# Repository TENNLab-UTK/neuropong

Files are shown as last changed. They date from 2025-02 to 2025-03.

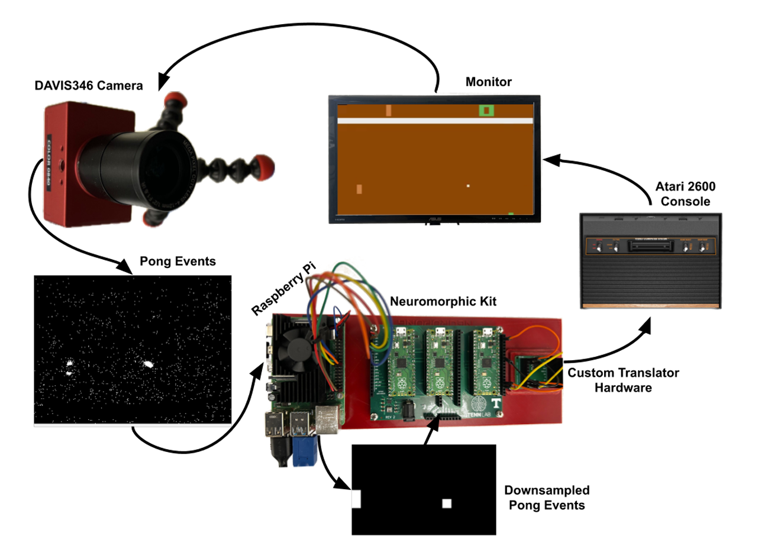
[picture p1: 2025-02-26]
imgs/NeuroPong_Physical_System.png

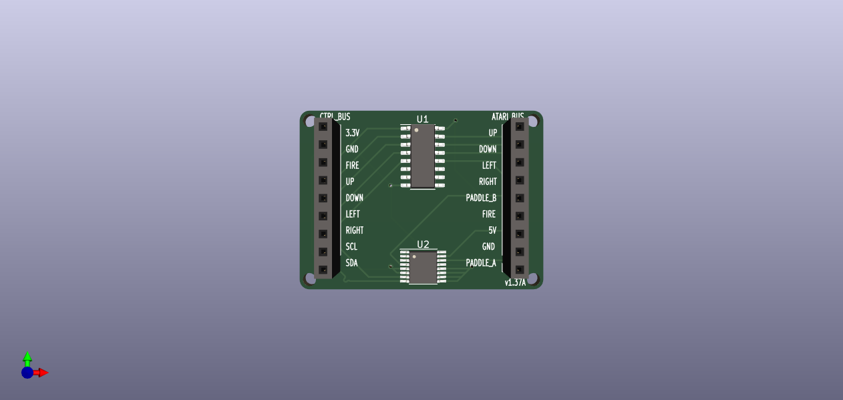
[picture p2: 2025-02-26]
pcb/pcb_v1_37A/ATARI_CTRL_PCB_1.37A_2.54mm.png

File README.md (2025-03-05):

# Neuropong
This is the repo contains the NeuroPong project files. NeuroPong is an embedded, neuromorphic Atari (Pong) agent. It marries an event-based camera, TENNLab's Neuromorphic Starter Kit (https://arxiv.org/abs/2211.04526), and an Atari 2600 console. Spiking neural networks are trained on simulated events created from frames generated by the Arcade Learning Environment, and then, those spiking neural networks are put on hardware to examine how they perform in a live setting using real event camera inputs.

## Prerequisites
Repositories needed to run existing spiking neural network agents:

- TENNLab Open-Source Framework: https://github.com/TENNLab-UTK/framework-open
- Inivation `dv-processing` Library: https://gitlab.com/inivation/dv/dv-processing
- TENNLab Embedded Neuromorphic repository(*):
    - Needed to compile code for Neuromorphic Starter Kit's Raspberry Pi Picos

(*) You will need to get access to this repo from Jim Plank (jplank@utk.edu) until it is open-sourced.

You will also need Python and a shell of some kind (bash/zsh) on Linux or Mac. It is recommended to set up a python virtual environment (Python <= 3.9) for compatability with Inivation event camera library.

## Contents

- **/models**: STL models of 3D printed objects used in this project for the presented prototype

- **/kit-code**: Contains code used by `embedded-neuromorphic/` repo to compile kit code.

- **/pcb**: Repo containing KiCad files for the PCB that contains the Atari Translator circuit

- **/scripts**: Scripts used to assist with flashing Picos and compiling kit code. `calibration.py` and `event_server.py` are used on the Raspberry Pi (or whatever is communicating with the Neuromorphic Starter Kit)

- **/imgs**: Contains various diagrams and images detailing parts of the NeuroPong system

- **/networks**: Contains the networks generated for the Neuropong paper.  

## Table of Hardware Materials/Components

| | Part | Quantity | Cost |
|:--:| ---: | ---: | ----: |
| | PCB Design |  1 | $4.11 |
| | AD5242 | 1 | $4.55 |
| | ULN2008 |  1 (unused) | $3.95 |
| | Female pin strips |  2 | $26.00 |
| | Raspberry Pi 4 |  1  | $75.00 |
| | MicroSD Card |  1 | $13.50 |
| | Breakout Cable |  1 | $20.00 |
|**Neuromorphic Starter Kit** |  | |  |
| | PCB Design |  1  | $10.65 |
| | Raspberry Pi Pico | 3 | $15.00 |
| | Power Supply | 1 | $7.69 |
| **Total** | | | $180.45 | 

* The Atari 2600 console and VideoOlympics cartridge together were ~$20.00.
* The DAVIS346 camera used for this project was purchased from [Inivation] (https://shop.inivation.com/).

## Running the Hardware Setup

1. Turn on monitor, put VideoOlympics cartridge in Atari 2600 console, and turn on the Atari console.
    - You should see the Pong game appear on the screen.
2. Plug NeuroPong controller into the back of one of the Atari controller ports.
    - *NOTE: you will need to make the NeuroPong cable. An detailed construction diagram can be found in the `/imgs` folder*
4. Power on the Raspberry Pi, and plug DAVIS346 camera into one of the USB ports on the Raspberry Pi.
5. Compile the network using `app_compile` from the `embedded_neuromorphic/` repo
    - Ex: `./bin/app_compile -j network_file -o kit-code/pico-pong_observations.c -a kit-code/pico-pong_actions[2,3].c -s`
6. Flash the three Raspberry Pi Picos on the kit with the appropriate encoder, decoder, and network. 
7. Power on the Neuromorphic Kit
8. On the Raspberry Pi, run `scripts/calibration.py` to assist with focusing the lens and cropping the camera's FOV to the screen.
    - The output produced by `scripts/calibration.py` is the command that is used to run `scripts/event_server.py`.
        - It figures out what the crop coordinates are and what the downsampling parameters need to be to match whatever the target downsampled resolution is. Target resolution is specified via global variables in the `scripts/calibration.py` program.
9. Run the command output by `scripts/calibration.py`
    - Ex: `python3 event_server.py --crop ...`
10. Wait 20-30 seconds for the system to initialize. If it's unreponsive, CTRL-C the event_server process and rerun it.
11. Begin the Atari game by toggling the ``Game Reset'' switch on the Atari system.
     
## Running the networks in the `framework-open` processor_tool

You may want to run the networks using `framework-open/bin/processor_tool` in order to view spike rasters for a network at each timestep during an episode of that network playing Pong in the Arcade Learning Environment. In `networks/processor_tool_commands` are the commands for the processor tool, for each of the 32 networks, for one 2000 frame Pong episode each. Each file in `networks/processor_tool_commands` contains the Apply_Spike (AS) commands that communicate the event simulated and downsampled representation of each frame as they're generated by the ALE online. To run, do the following:

            ```
            UNIX> pwd
            .../neuropong
            UNIX> ./framework-open/bin/processor_tool_risp < networks/processor_tool_commands/pong0.txt
            0   INPUT  :    // No inputs are provided to the network during the first frame or timestep, so the spike raster is empty
            1   INPUT  : 
            2   INPUT  : 
            3   INPUT  : 
            4   INPUT  : 
            5   INPUT  : 
            6   INPUT  : 
            7   INPUT  : 
            8   INPUT  : 
            9   INPUT  : 
            10  INPUT  : 
            11  INPUT  : 
            12  INPUT  : 
            13  INPUT  : 
            14  INPUT  : 
            15  INPUT  : 
            16  INPUT  : 
            17  INPUT  : 
            18  INPUT  : 
            19  INPUT  : 
            20  INPUT  : 
            21  INPUT  : 
            22  INPUT  : 
            23  INPUT  : 
            24  INPUT  : 
            25  INPUT  : 
            26  INPUT  : 
            27  INPUT  : 
            28  INPUT  : 
            29  INPUT  : 
            30  INPUT  : 
            31  INPUT  : 
            32  INPUT  : 
            33  INPUT  : 
            34  INPUT  : 
            35  INPUT  : 
            36  INPUT  : 
            37  INPUT  : 
            38  INPUT  : 
            39  INPUT  : 
            40  INPUT  : 
            41  INPUT  : 
            42  INPUT  : 
            43  INPUT  : 
            44  INPUT  : 
            45  INPUT  : 
            46  INPUT  : 
            47  INPUT  : 
            48  INPUT  : 
            49  INPUT  : 
            50  INPUT  : 
            51  INPUT  : 
            52  INPUT  : 
            53  INPUT  : 
            54  INPUT  : 
            55  INPUT  : 
            56  INPUT  : 
            57  INPUT  : 
            58  INPUT  : 
            59  INPUT  : 
            60  INPUT  : 
            61  INPUT  : 
            62  INPUT  : 
            63  INPUT  : 
            64  INPUT  : 
            65  INPUT  : 
            66  INPUT  : 
            67  INPUT  : 
            68  INPUT  : 
            69  INPUT  : 
            70  INPUT  : 
            71  INPUT  : 
            72  INPUT  : 
            73  INPUT  : 
            74  INPUT  : 
            75  INPUT  : 
            76  INPUT  : 
            77  INPUT  : 
            78  INPUT  : 
            79  INPUT  : 
            80  INPUT  : 
            81  INPUT  : 
            82  INPUT  : 
            83  INPUT  : 
            84  INPUT  : 
            85  INPUT  : 
            86  INPUT  : 
            87  INPUT  : 
            88  INPUT  : 
            89  INPUT  : 
            90  INPUT  : 
            91  INPUT  : 
            92  INPUT  : 
            93  INPUT  : 
            94  INPUT  : 
            95  INPUT  : 
            96  INPUT  : 
            97  INPUT  : 
            98  INPUT  : 
            99  INPUT  : 
            100 INPUT  : 
            101 INPUT  : 
            102 INPUT  : 
            103 INPUT  : 
            104 INPUT  : 
            105 INPUT  : 
            106 INPUT  : 
            107 INPUT  : 
            108 INPUT  : 
            109 INPUT  : 
            110 INPUT  : 
            111 INPUT  : 
            112 INPUT  : 
            113 INPUT  : 
            114 INPUT  : 
            115 INPUT  : 
            116 INPUT  : 
            117 INPUT  : 
            118 INPUT  : 
            119 INPUT  : 
            120 INPUT  : 
            121 INPUT  : 
            122 INPUT  : 
            123 INPUT  : 
            124 INPUT  : 
            125 INPUT  : 
            126 INPUT  : 
            127 INPUT  : 
            128 INPUT  : 
            129 INPUT  : 
            130 INPUT  : 
            131 INPUT  : 
            132 INPUT  : 
            133 INPUT  : 
            134 INPUT  : 
            135 INPUT  : 
            136 INPUT  : 
            137 INPUT  : 
            138 INPUT  : 
            139 INPUT  : 
            140 INPUT  : 
            141 INPUT  : 
            142 INPUT  : 
            143 INPUT  : 
            144 INPUT  : 
            145 INPUT  : 
            146 INPUT  : 
            147 INPUT  : 
            148 INPUT  : 
            149 INPUT  : 
            150 INPUT  : 
            151 INPUT  : 
            152 INPUT  : 
            153 INPUT  : 
            154 INPUT  : 
            155 INPUT  : 
            156 INPUT  : 
            157 INPUT  : 
            158 INPUT  : 
            159 INPUT  : 
            160 OUTPUT : 
            161 OUTPUT : 
            162 OUTPUT : 
            0   INPUT  : 1000000000100100100000000000000000000000000000000 // Now, during the second frame/timestep, we apply a spike to  
            1   INPUT  : 1000000000000000000000000000000000000000000000000 // the appropriate input neurons and run the network for 50 cycles. 
            2   INPUT  : 1010000001000000010011000000000010000000000000000 // The columns represent the network timestep 
            3   INPUT  : 1000000000000000000000000000000000000000000000000 // and a "1" represents a neuronal fire.
            4   INPUT  : 1000000000000111100100100000001000100000000001000
            5   INPUT  : 1000000000000000000000000000000000000000000000000
            6   INPUT  : 1000000000000000000000000000000000000000000000000
            7   INPUT  : 1000000000000000000000000000000000000000000000000
            8   INPUT  : 1000000000000000000000000000000000000000000000000
            9   INPUT  : 1000000000000000000000000000000000000000000000000
            10  INPUT  : 1000000000000000000000000000000000000000000000000
            11  INPUT  : 1000000000000000000000000000000000000000000000000
            12  INPUT  : 1000000000000000000000000000000000000000000000000
            13  INPUT  : 1000000000000000000000000000000000000000000000000
            14  INPUT  : 1000000000000000000000000000000000000000000000000
            15  INPUT  : 1000000000000000000000000000000000000000000000000
            16  INPUT  : 1000000000100000000000000000000000000000000000000
            17  INPUT  : 1000000000000000000000000000000000000000000000000
            18  INPUT  : 1000000000000000000000000000000000000000000000000
            19  INPUT  : 1000000000000000000000000000000000000000000000000
            20  INPUT  : 1000000000000010000000000000000000000000000000000
            21  INPUT  : 1000000000000000000000000000000000000000000000000
            22  INPUT  : 1000000001000000000000000000000000000000000000000
            23  INPUT  : 1001000000000000000000000000000000000000000000000
            24  INPUT  : 1000000000000000000000000000000000000000000000000
            25  INPUT  : 1000000000000000000000000000000000000000000000000
            26  INPUT  : 1000000000000000000000000000000000000000000000000
            27  INPUT  : 1000010000000000000000000000000000000000000000000
            28  INPUT  : 1000000000000000000000000000000000000000000000000
            29  INPUT  : 1000000001010000000000000000000000000000000000000
            30  INPUT  : 1000000000000000000000000000000000000000000000000
            31  INPUT  : 1000000000000000000000000000000000000000000000000
            32  INPUT  : 1000000000000000000000000000000000000000000000000
            33  INPUT  : 1000000000000000000000000000000000000000000000000
            34  INPUT  : 1000000000000000000000000000000000000000000000000
            35  INPUT  : 1000000000000000000000000000000000000000000000000
            36  INPUT  : 1000000000000000000000000000000000000000000000000
            37  INPUT  : 1000000000000000000000000000000000000000000000000
            38  INPUT  : 1000000010000000000000000000000000000000000000000
            39  INPUT  : 1000000000000000000000000000000000000000000000000
            40  INPUT  : 1000000000010000000000000000000000000000000000000
            41  INPUT  : 1000000000000000000000000000000000000000000000000
            42  INPUT  : 1000000000000000000000000000000000000000000000000
            43  INPUT  : 1000000000000000000000000000000000000000000000000
            44  INPUT  : 1000000000000000000000000000000000000000000000000
            45  INPUT  : 1000000000000000000000000000000000000000000000000
            46  INPUT  : 1000000000000000000000000000000000000000000000000
            47  INPUT  : 1000000000000000000000000000000000000000000000000
            48  INPUT  : 1000000000010000000000000000000000000000000000000
            49  INPUT  : 1000000000000000000000000000000000000000000000000
            50  INPUT  : 1000000000010000000000000000000000000000000000000
            51  INPUT  : 1000000100000000000000000000000000000000000000000
            52  INPUT  : 1000000000000000000000000000000000000000000000000
            53  INPUT  : 1000000000000000000000000000000000000000000000000
            54  INPUT  : 1000000000000000000000000000000000000000000000000
            55  INPUT  : 1000000000000000000000000000000000000000000000000
            56  INPUT  : 1000000000000000000000000000000000000000000000000
            57  INPUT  : 1000000000000000000000000000000000000000000000000
            58  INPUT  : 1001010000000110000000000001111001001000000010001
            59  INPUT  : 1000100000000001000000000000000000000000000000000
            60  INPUT  : 1000000000000000000000000000000000000000000000000
            61  INPUT  : 1000000000010000000000000000000000000000000000000
            62  INPUT  : 1000000000000000000000000000000000000000000000000
            63  INPUT  : 1000000000000000000000000000000000000000000000000
            64  INPUT  : 1100010100100100000000000000000000000000000000000
            65  INPUT  : 1000000000000000000000000000000000000000000000000
            66  INPUT  : 1010010010000000000000000000000000000000000000000
            67  INPUT  : 1000000000010000000000000000000000000000000000000
            68  INPUT  : 1000000000000000000000000000000000000000000000000
            69  INPUT  : 1001000000000000000000000000000000000000000000000
            70  INPUT  : 1000010000000000000000000000000000000000000000000
            71  INPUT  : 1000000000000000000000000000000000000000000000000
            72  INPUT  : 1000000000000000000000000000000000000000000000000
            73  INPUT  : 1000000000000000000000000000000000000000000000000
            74  INPUT  : 1000000000000000000000000000000000000000000000000
            75  INPUT  : 1000000000000001000000000000000000000000000000000
            76  INPUT  : 1000000000000000000000000000000000000000000000000
            77  INPUT  : 1000000000000000000000000000000000000000000000000
            78  INPUT  : 1001011000100000000000000100000000000000000000000
            79  INPUT  : 1000000000000000000000000000000000000000000000000
            80  INPUT  : 1000000000000000000000000000000000000000000000000
            81  INPUT  : 1000000000000000000000000000000000000000000000000
            82  INPUT  : 1000000000000000000000000000000000000000000000000
            83  INPUT  : 1000000000000000000000000000000000000000000000000
            84  INPUT  : 1000000000000000000000000000000000000000000000000
            85  INPUT  : 1000000000000000000000000000000000000000000000000
            86  INPUT  : 1000000000000000000000000000000000000000000000000
            87  INPUT  : 1000000000000000000000000000000000000000000000000
            88  INPUT  : 1000000000000000000000000000000000000000000000000
            89  INPUT  : 1000000000000000000000000000000000000000000000000
            90  INPUT  : 1000000000000000000000000000000000000000000000000
            91  INPUT  : 1000000000000000000000000000000000000000000000000
            92  INPUT  : 1000000000000000000000000000000000000000000000000
            93  INPUT  : 1000000000000000000000000000000000000000000000000
            94  INPUT  : 1000000000000000000000000000000000000000000000000
            95  INPUT  : 1000000000000000000000000000000000000000000000000
            96  INPUT  : 1000000000100001000000000010000000000000000000000
            97  INPUT  : 1000000000000000000000000000000000000000000000000
            98  INPUT  : 1010000000000000000000000000000000000000000000000
            99  INPUT  : 1000000000000000000000000000000000000000000000000
            100 INPUT  : 1000000000000000000000000000000000000000000000000
            101 INPUT  : 1000000100000000000000000000000000000000000000000
            102 INPUT  : 1000000000000000000000000000000000000000000000000
            103 INPUT  : 1000000000000000000000000000000000000000000000000
            104 INPUT  : 1000000000000000000000000000000000000000000000000
            105 INPUT  : 1000000000000000000000000000000000000000000000000
            106 INPUT  : 1000000000000000000000000000000000000000000000000
            107 INPUT  : 1000000000000000000000000000000000000000000000000
            108 INPUT  : 1000000000000000000000000000000000000000000000000
            109 INPUT  : 1000000000000000000000000000000000000000000000000
            110 INPUT  : 1000000000000000000000000000000000000000000000000
            111 INPUT  : 1000000000000000000000000000000000000000000000000
            112 INPUT  : 1000000000000000000000000000000000000000000000000
            113 INPUT  : 1001001000000000000000000000000000000000000000000
            114 INPUT  : 1000000000000000000000000000000000000000000000000
            115 INPUT  : 1000000000000000000000000000000000000000000000000
            116 INPUT  : 1000000000000000000000000000000000000000000000000
            117 INPUT  : 1000000000000000000000000000000000000000000000000
            118 INPUT  : 1000000000100000000000010000000000100000000000000
            119 INPUT  : 1000000000000000000000000000000000000000000000000
            120 INPUT  : 1000000000000100000000001000000000000000000000000
            121 INPUT  : 1000000000000000000000000000000000000000000000000
            122 INPUT  : 1010000000000000010000000000000000000000000000000
            123 INPUT  : 1000000000000000000000000000000000000000000000000
            124 INPUT  : 1000000000000000000000000000000000000000000000000
            125 INPUT  : 1000000000000000000000000000000000000000000000000
            126 INPUT  : 1000000000000000000000000000000000000000000000000
            127 INPUT  : 1000000000000000000000000000000000000000000000000
            128 INPUT  : 1000000000000000000000000000000000000000000000000
            129 INPUT  : 1011000100000000000000100000000000000000000000000
            130 INPUT  : 1000000000000000000000000000000000000000000000000
            131 INPUT  : 1000000000000000000000000000000000000000000000000
            132 INPUT  : 1000000000000000000000000000000000000000000000000
            133 INPUT  : 1000000000000001000000000000000000000000000000000
            134 INPUT  : 1000000000000000000000000000000000000000000000000
            135 INPUT  : 1010000000000000000000000000000000000000000000000
            136 INPUT  : 1000000000000000000000000000000000000000000000000
            137 INPUT  : 1000000000000000000000000000000000000000000000000
            138 INPUT  : 1000000000000000000000000000000000000000000000000
            139 INPUT  : 1000000000000000000000000000000000000000000000000
            140 INPUT  : 1000000000000000000000000000000000000000000000000
            141 INPUT  : 1000000000000000000000000000000000000000000000000
            142 INPUT  : 1000000010000000000000000000000000000000000000000
            143 INPUT  : 1000000000000000000000000000000000000000000000000
            144 INPUT  : 1000000100000001000100000000001000000000000000000
            145 INPUT  : 1000000000000000000000000000000000000000000000000
            146 INPUT  : 1000000000000000000000000000000000000000000000000
            147 INPUT  : 1000000000000000000000000000000000000000000000000
            148 INPUT  : 1000100000000000000000000000000000000000000000000
            149 INPUT  : 1000000000000000000000000000000000000000000000000
            150 INPUT  : 1100010000000000000010000000000000000000000000000
            151 INPUT  : 1000000000000000000000000000000000000000000000000
            152 INPUT  : 1000000000000000000000000000000000000000000000000
            153 INPUT  : 1000000000000000000000000000000000000000000000000
            154 INPUT  : 1010000000000000000000000000000000000000000000000
            155 INPUT  : 1000000000000000000000000000000000000000000000000
            156 INPUT  : 1000000000000000000000000000000000000000000000000
            157 INPUT  : 1000000000000000000000000000000000000000000000000
            158 INPUT  : 1000000100000010000000000000000000000000000000000
            159 INPUT  : 1000000000000000000000000000000000000000000000000
            160 OUTPUT : 0000100101000000011000000000000111100100100000001 // At the end of our 50 timesteps, we count the output fires on the
            161 OUTPUT : 0000000010000000000000000000000000000000000000000 // three output neurons. Whoever fired the most "wins", and its
            162 OUTPUT : 0000000001000100000000000000000000000000000000000 // action is the action performed by the network for that frame
            ...                                                            // from the ALE.
            ...
            ```

More information about `processor_tool_risp` can be found in the `framework-open/markdown/` directory. This is provided as a method for you to see how the network acts when provided event-simulated and downsampled ALE frames.

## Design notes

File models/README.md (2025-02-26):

# 3d Models used in this project
These files include the chassis that held individual components and the PCB enclosure for the Atari Translator PCB Module.

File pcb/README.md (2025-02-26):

# Atari CTRL PCB
This folder contains the KiCad source files along with some renders of what the PCB looks like

# Components
1. Digital Potentiometer - AD5242
    - Function: Emulate paddle controller analogue signal
    - https://www.digikey.com/en/products/detail/analog-devices-inc/AD5242BRUZ1M/997427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
2. Darlington Transistor Pair - ULN2003A
    - Function: Emulate button presses from joystick controller (negative logic)
    - Note: When button is pressed, the input pin (UP/DOWN/LEFT/RIGHT/FIRE) is shorted from floating voltage to ground (0 V)
    - https://www.digikey.com/en/products/detail/texas-instruments/ULN2003ADR/277011

## Case Incompatability Disclosure 
**NOTE**: The PCB Case Lid is only compatible with 1.25A version of the case. This is due to the connector size changes from 2.00mm connector (v1.27) to a 2.54mm connector (1.37A). 

## Pinout Disclosure
**NOTE**: The PCB design does not utilize the 5V rail from the Atari to avoid voltage mismatches on the digital potentiometer output.

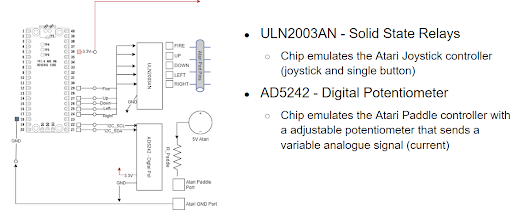
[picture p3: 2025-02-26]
imgs/decoderDiagram.png

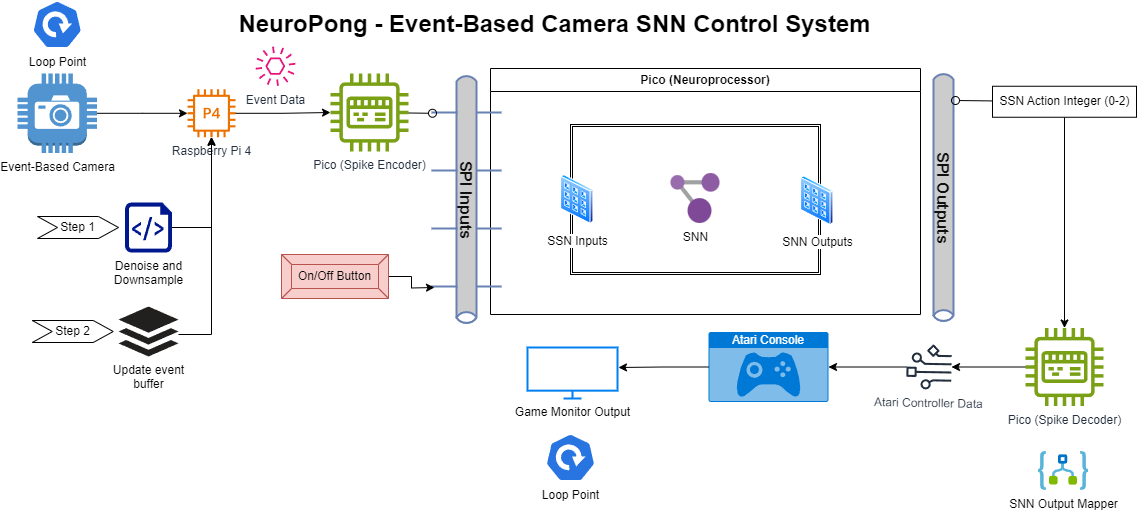
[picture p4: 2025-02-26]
imgs/NeuroPong_System_Diagram-System Diagram.png

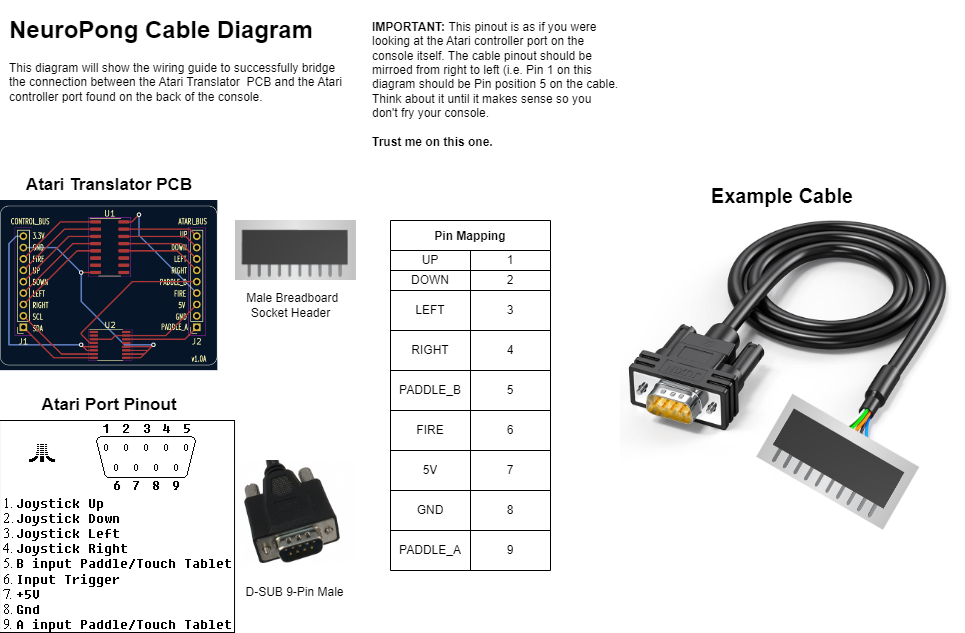
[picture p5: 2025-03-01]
imgs/NeuroPong_Cable.drawio.png

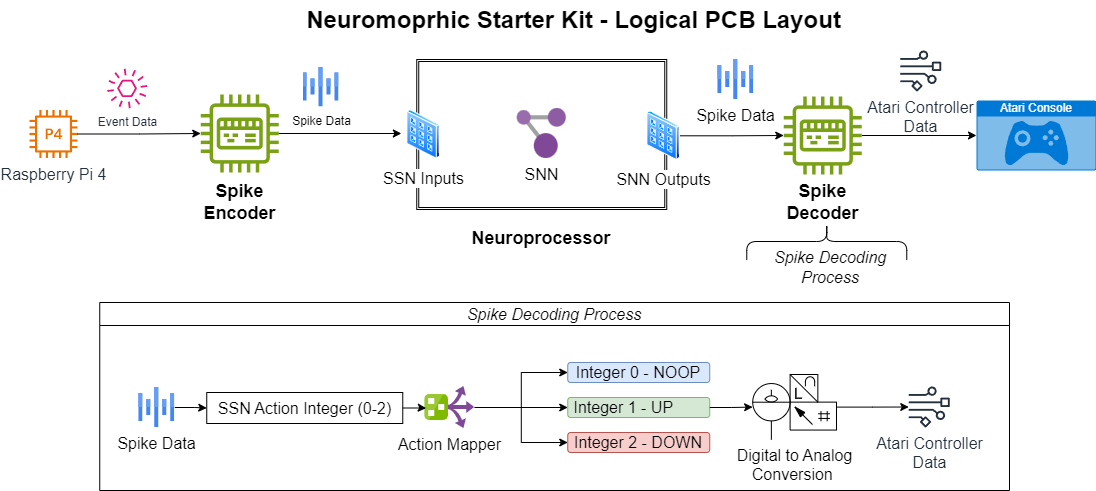
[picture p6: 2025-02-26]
imgs/NeuroPong_System_Diagram-System Data Flow.png

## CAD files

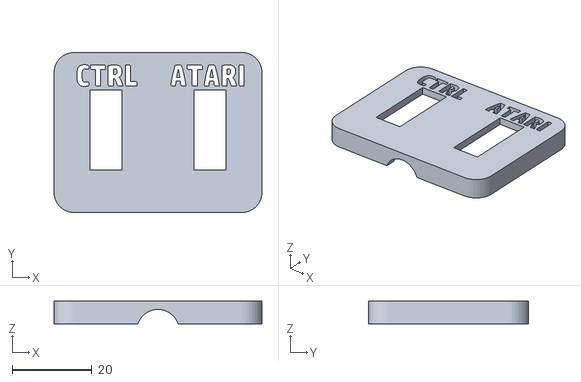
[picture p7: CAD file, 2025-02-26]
models/pcb_case/ATARI_Enclosure_Lid.STL
52.0 x 40.0 x 5.63

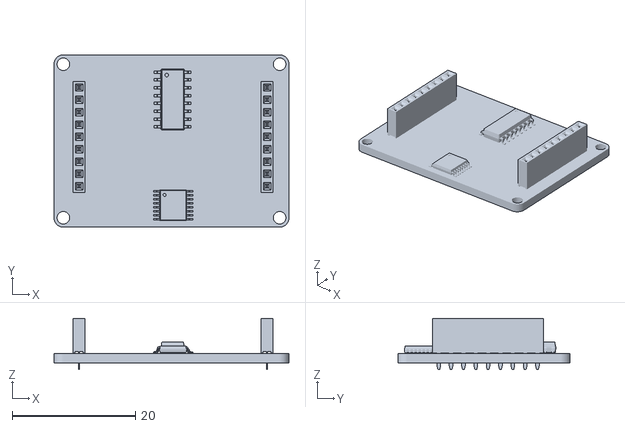
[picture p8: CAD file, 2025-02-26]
models/pcb_case/ATARI PCB.STL
38.1 x 27.9 x 8.30

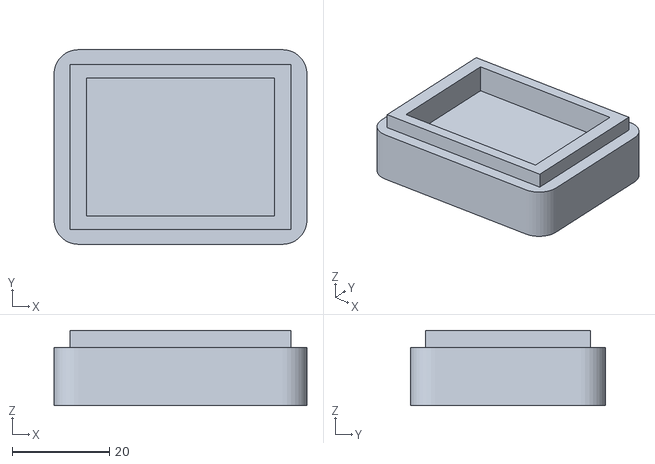
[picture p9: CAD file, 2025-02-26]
models/pcb_case/ATARI_CTRL_PCB Case.STL
52.0 x 40.0 x 15.5

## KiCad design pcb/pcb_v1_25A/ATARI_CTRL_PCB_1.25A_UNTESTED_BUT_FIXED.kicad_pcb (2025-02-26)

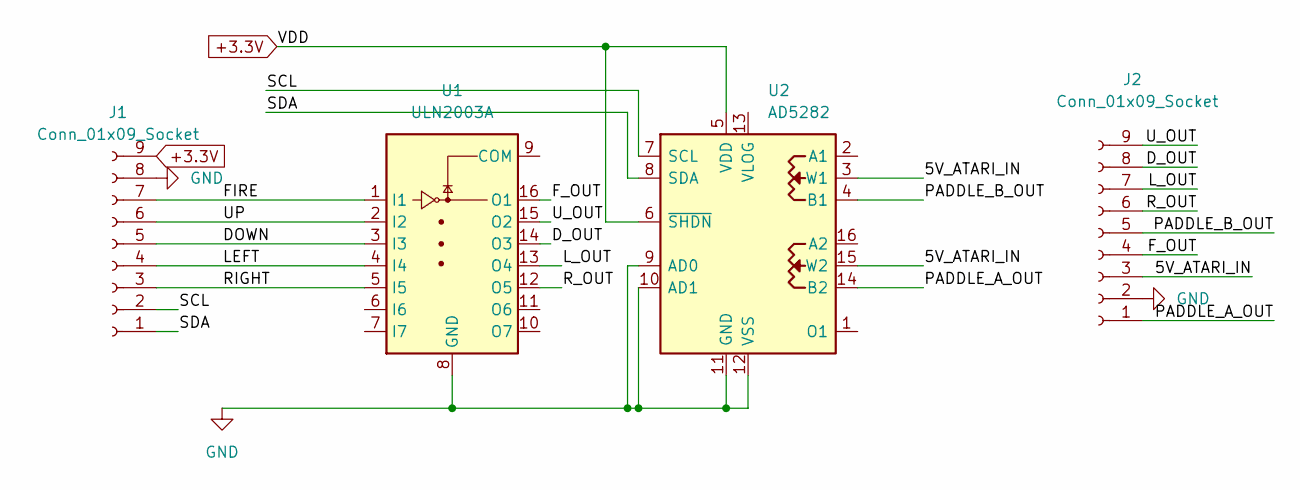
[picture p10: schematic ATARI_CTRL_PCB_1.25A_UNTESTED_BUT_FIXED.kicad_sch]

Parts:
J1, J2: Conn_01x09_Socket; PinSocket_1x09_P2.00mm_Vertical
U1: ULN2003A; SOIC-16_3.9x9.9mm_P1.27mm
U2: AD5282; TSSOP-16_4.4x5mm_P0.65mm

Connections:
+3.3V: J1.9, U2.5 (VDD), U2.6 (~SHDN)
/5V_ATARI_IN: J2.3, U2.3 (W1), U2.15 (W2)
/DOWN: J1.5, U1.3 (I3)
/D_OUT: J2.8, U1.14 (O3)
/FIRE: J1.7, U1.1 (I1)
/F_OUT: J2.4, U1.16 (O1)
/LEFT: J1.4, U1.4 (I4)
/L_OUT: J2.7, U1.13 (O4)
/PADDLE_A_OUT: J2.1, U2.14 (B2)
/PADDLE_B_OUT: J2.5, U2.4 (B1)
/RIGHT: J1.3, U1.5 (I5)
/R_OUT: J2.6, U1.12 (O5)
/SCL: J1.2, U2.7 (SCL)
/SDA: J1.1, U2.8 (SDA)
/UP: J1.6, U1.2 (I2)
/U_OUT: J2.9, U1.15 (O2)
GND: J1.8, J2.2, U1.8 (GND), U2.9 (AD0), U2.10 (AD1), U2.11 (GND), U2.12 (VSS)

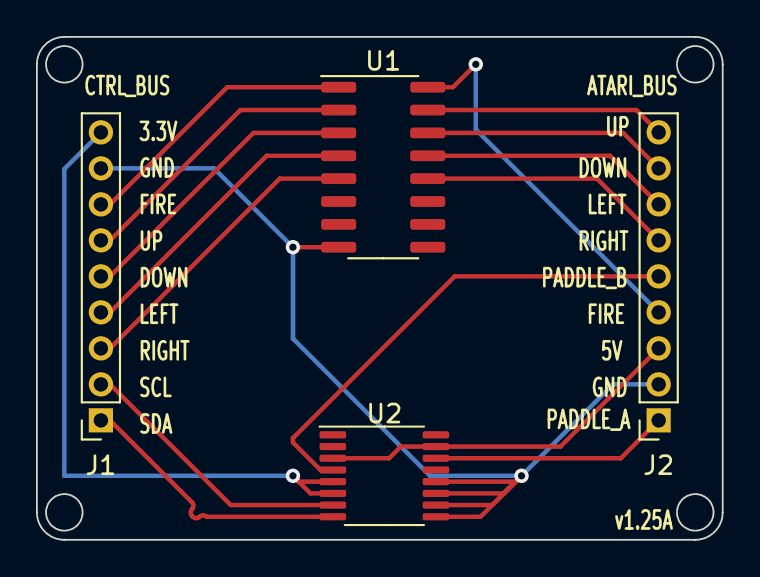
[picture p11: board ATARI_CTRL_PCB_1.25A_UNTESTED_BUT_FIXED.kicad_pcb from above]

Board: 2 copper layers, 38.1 x 27.9 mm, 4 parts (0 on the bottom side), 17 nets.

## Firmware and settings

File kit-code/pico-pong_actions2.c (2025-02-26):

#include <actions.h>
#include <stdio.h>
#include <stdlib.h>
#include "pico/stdio.h"
#include "pico/stdlib.h"
#include "hardware/gpio.h"
#include "hardware/i2c.h"
// TODO: Update primary repo with pin updates (maybe not necessary)
#define I2C_PORT i2c0
#define REFRESH_RATE 33 // 60 Hz Refres rate 
const uint LED_PIN = PICO_DEFAULT_LED_PIN;

//const uint POT_MIN = 0xB0; // Represents the PONG bar at the bottom of screen
//const uint POT_MAX = 0xEE; // Represents the PONG bar at the top of screen

// New bounds based on using Pico 3.3V rail - had to swap output ports, therefore NEW_MIN = (0xFF - POT_MIN)
const uint POT_MIN = 0x0A; // Represents the PONG bar at the bottom of screen
const uint POT_MAX = 0x2b; // Represents the PONG bar at the top of screen
// ^^^^^^^ Adjusted above bounds for dead zones

const uint POT_MAX_OHM = 1000000;
const uint I2C_SCL_POT = 1;
const uint I2C_SDA_POT = 0;
static uint addr = 0x2C; // Read datasheet of AD5241 device for addr specifics
static uint instr = 0x80; /* Instruction byte to adjust RDAC2 (Digital POT 2) on the AD5242 device 
                            Midscale reset is turned off, and the shutdown feature is off
                            Output logic pins on chip are both set to 0              */

uint8_t paddle_pos = (POT_MIN + POT_MAX) / 2; // Global variable for tracking paddle position between loop_use_actions() executions
double ohms = 0; // Global variable to track ohm reading

const uint8_t step_size = 4;
const uint8_t jitter_size = 2;

/* FULL Output Mapping (Network Simulation to Atari Output
 *
 * KEY:
[ SIMULATED ACTION    ] -> [ ALE MAPPING    ] -> [ ENCODER MAPPING  ] -> [ POT CHANGE ] -> [ OHM Change ] -> [ ATARI OUTPUT ]

[ DONT MOVE ON SCREEN ] -> [ NOOP       - 0 ] -> [NETWORK ACTION - 0] -> [ +0         ] -> [   NONE     ] -> [ STAY         ]
[ MOVE UP ON SCREEN   ] -> [ MOVE RIGHT - 3 ] -> [NETWORK ACTION - 1] -> [ -STEP      ] -> [ + OHM      ] -> [ UP           ]
[ MOVE DOWN ON SCREEN ] -> [ MOVE LEFT  - 4 ] -> [NETWORK ACTION - 2] -> [ +STEP      ] -> [ - OHM      ] -> [ DOWN         ]
*/

/*
 * Jitters pong paddle on screen slightly
 *   - Useful for helping the event-based camera continue to see the paddle
 *   even if it is stuck on the top or bottom of the screen
 */
void jitter(uint8_t val); // Jitters pong paddle on screen slightly 


/*
 * Jitters pong paddle on screen slightly
 *   - Useful for helping the event-based camera continue to see the paddle
 *   even if it is stuck on the top or bottom of the screen
 */
void jitter(uint8_t val); // Jitters pong paddle on screen slightly 

uint8_t update_paddle(double actions[], uint8_t num_actions, uint8_t val, uint8_t step_size){
  uint8_t new_val = val;
	printf("num_actions: %d\n",num_actions);
  //printf("num_actions = %u\n", num_actions); 
  for (uint8_t i = 0; i < num_actions; ++i) {
    switch ( (int) actions[i] ) {
    /* presumably MOVE_RIGHT */
    case 0:
   //   printf("action %u: MOVE_RIGHT\n", i);
      new_val += step_size;
      break;

    /* presumably MOVE_LEFT */
    case 1:
     // printf("action %u: MOVE_LEFT\n", i);
      new_val -= step_size;
      break;
    
    default:
      printf("error in update_paddle: action %d not recognized\n", (int) actions[i]);
      exit(1);
    }
  }
  // Check boundary conditions (TODO: remove if the SNN isn't moving to where it wants to go)
  if (new_val > POT_MAX) return POT_MAX;
  if (new_val < POT_MIN) return POT_MIN;
  return new_val;
}

void update_pot(uint8_t val){ // These check conditions might be dumb. Might just overflow to save number
  int ret = 0; 
  if (val < 0 || val > 255){
    //printf("Invalid POT value. Exiting Program\n");
    gpio_put(LED_PIN, 0);
    exit(-1);
  }
  uint8_t buf[2] = {instr,val}; 
  ret = i2c_write_blocking(I2C_PORT, addr, buf, 2, false); 
  //if (ret == PICO_ERROR_GENERIC) printf("Error on I2C Bus\n");
  return;

}

void jitter(uint8_t val){
  
  uint8_t right = val + jitter_size;
  uint8_t left = val - jitter_size;
  // Ensures that maximum bounds are not exceeded (causes hard fault) 
  if (right > POT_MAX) right = POT_MAX;
  if (left < POT_MIN) left =  POT_MIN;
  
  // Sleeps in between each position update to give Atari time to react 
  update_pot(right);
  sleep_ms(33);
  update_pot(left);
  sleep_ms(33);
  update_pot(val);

  return;
}


uint8_t read_pot(){
  uint8_t output; 
  i2c_read_blocking(I2C_PORT, addr, &output, 1, false);
//  printf("POT Value: %x\n",output);
  return output; 
}

/* User defined: Use this procedure to perform any setup needed to utilize the
action values retrieved from the output of the neuroprocessor's network. Called
once.
    Arguments:
        - available_pins : Pins available for user to use as desired
        - num_available_pins : Number of pins available for user use
*/
void setup_use_actions(const uint8_t available_pins[], uint8_t num_available_pins) {
  // Setup output LED PIN    
  gpio_init(LED_PIN);
  gpio_set_dir(LED_PIN, GPIO_OUT);
  gpio_put(LED_PIN,0); 

  /* Setup I2C Protocol for I2C0 @ 400kHz 
  with GPIO 1 (SDL) and GPIO 0 (SDA)*/
  i2c_init(I2C_PORT, 400000);
  gpio_set_function(I2C_SCL_POT, GPIO_FUNC_I2C);
  gpio_set_function(I2C_SDA_POT, GPIO_FUNC_I2C);
  gpio_pull_up(I2C_SCL_POT);
  gpio_pull_up(I2C_SDA_POT);

  return;
}

/* User defined: Use this procedure to utilize action values retrieved from the
output of the neuroprocessor's network. Called repeatedly.
    Arguments:
        - actions : Array of double action values
        - num_actions : Number of action values in actions array
        - available_pins : Pins available for user to use as desired
        - num_available_pins : Number of pins available for user use
*/
void loop_use_actions(double actions[], uint8_t num_actions, const uint8_t available_pins[], uint8_t num_available_pins) {
  double ohms;

  /*
  if (num_actions > 1){
    printf("ERROR: Wrong number of actions (expecting only 1)"); 
    return; 
  }
  */
  //printf("received action %d\n", (int) actions[0]);

  paddle_pos = update_paddle(actions, num_actions, paddle_pos, step_size); 
  ohms = ((double) paddle_pos / 256) * POT_MAX;
 
  //printf("Setting POT to %x ( %3.2f ohms)\n", paddle_pos, ohms);
  update_pot(paddle_pos);

  // Heartbeat
  gpio_put(LED_PIN, !gpio_get(LED_PIN));    
  //sleep_ms(REFRESH_RATE); // Might be uneccessary due to SNN timing TODO: see if this needs to be removed
  read_pot(); 
}

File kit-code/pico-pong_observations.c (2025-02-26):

/*
Handling input to spike encoder for binary to decimal converter:
    - Outputs list of binary digits on every iteration
        - Defaults to output of zero, until non-zero signal detected for 3 loops
        - DOES NOT TRACK COLLECTIVE CONSISTENCY OF VALUES, JUST INDIVIDUAL
    - Highest to lowest base goes from lowest button to highest
        - Current implementation: BUTTON_1 = 4s place, BUTTON_2 = 2s place, BUTTON_3 = 1s place
*/

#include <observations.h>
#include <stdio.h>
#include "pico/stdlib.h"
#include "hardware/spi.h"

// Define SPI pins
#define SPI_PORT spi0
#define SPI_RDY_PIN 1 // Active high PIN (ready for transfer when  PIN == 3.3V)
#define SPI_SCK_PIN 2
#define SPI_TX_PIN 3
#define SPI_RX_PIN 4
#define SPI_CS_PIN 5

const uint LED_PIN = PICO_DEFAULT_LED_PIN;

#define  OBS_ARR_LENGTH 160
uint8_t observation_arr[OBS_ARR_LENGTH];


void get_observations(){
  int ret = 0;
  uint8_t tmp_rec_array[OBS_ARR_LENGTH];
  //uint8_t tmp_send_array[OBS_ARR_LENGTH] = {0xA};
  // Turn sync pin low to show ready state
  gpio_put(SPI_RDY_PIN, 1);

  // Write dummy bits to SPI and get data from SPI interface
  for(unsigned int i = 0; i < OBS_ARR_LENGTH; i++){

    spi_read_blocking(SPI_PORT,0xff, tmp_rec_array+i,1);
  }
  // Turn sync PIN high to show not ready and input buffer should wait
  gpio_put(SPI_RDY_PIN, 0);
  //printf("Bytes Reads: %d\n",ret);
 // printf("Transfer Complete\n");
  //printf("Rec Array: ");
  // Update global array of observations to push to Neuroprocessor
  for (unsigned int i = 0; i < OBS_ARR_LENGTH; i++){
   //printf("%d ",tmp_rec_array[i]);
   observation_arr[i] = tmp_rec_array[i];
  }

  return;
}

void print_observations(){
    // Clear the console and position the cursor at the top-left corner
    printf("\033[H\033[J");

    for (unsigned int i = 0; i < OBS_ARR_LENGTH; i++) {
        printf("%1d ", observation_arr[i]); // Print each element in a fixed-width format
        if ((i + 1) % 16 == 0) { // Newline every 20 elements for better readability
            printf("\n");
        }
    }
    printf("\n");
  return;
}

/* User defined: Use this procedure to perform any setup needed to read/provide
observation values that are encoded into spikes that are inputted into the
neuroprocessor's network. Called once.
    Arguments:
        - available_pins : Pins available for user to use as desired
        - num_available_pins : Number of pins available for user use
*/

void setup_read_observations(const uint8_t available_pins[], uint8_t num_available_pins) {
  // Setup output LED PIN    
  gpio_init(LED_PIN);
  gpio_set_dir(LED_PIN, GPIO_OUT);
  gpio_put(LED_PIN,0);

  // Setup SPI control lines (synchronization)
  gpio_init(SPI_RDY_PIN);
  gpio_set_dir(SPI_RDY_PIN, GPIO_OUT);
  gpio_put(SPI_RDY_PIN, 0);

  // Initialize SPI interface
  spi_init(SPI_PORT, 1000 * 1000); // 1000 khz  clock rate
  gpio_set_function(SPI_SCK_PIN, GPIO_FUNC_SPI);
  gpio_set_function(SPI_TX_PIN, GPIO_FUNC_SPI);
  gpio_set_function(SPI_RX_PIN, GPIO_FUNC_SPI);
  gpio_set_function(SPI_CS_PIN, GPIO_FUNC_SPI);

  // Set up chip select, operating in slave mode
  spi_set_format(SPI_PORT, 8, SPI_CPOL_0, SPI_CPHA_0, SPI_MSB_FIRST);
  spi_set_slave(SPI_PORT, true);

  // Setup output LED PIN
  gpio_init(LED_PIN);
  gpio_set_dir(LED_PIN, GPIO_OUT);
  gpio_put(LED_PIN,1);
  //printf("IO INITED\n");
  return;
}

/* User defined: Use this procedure to provide an observation value to a spike
encoder that inputs spikes into the neuroprocessor's network. Called repeatedly.
    Arguments:
        - observation_ind : The index of the current observation (equals the
                            index of the current spike encoder)
*/
double loop_read_observation(uint8_t observation_ind) {
  int8_t observation = 0;
  
  if (observation_ind == 0){
    get_observations();
    //print_observations();
  }
 
   // Heartbeat
  gpio_put(LED_PIN, !gpio_get(LED_PIN));  
  return (double) (observation_arr[observation_ind]);

  
}

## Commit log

2025-02-26 Initial repo push
    [ATARI PCB.STL, ATARI_CTRL_PCB Case.STL, ATARI_CTRL_PCB_1.25A_UNTESTED_BUT_FIXED.kicad_pcb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]
2025-03-01 NeuroPong cable - Update README.md
2025-03-01 neuropong cable diagram for readme
